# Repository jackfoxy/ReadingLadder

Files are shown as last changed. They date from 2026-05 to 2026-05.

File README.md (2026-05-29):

# ReadingLadder

A one-piece furniture design: a floor-standing **reading lectern** on the front,
**steps** climbing the back to a **top platform** for reaching high shelves, with
a front **book cubby** (3 compartments), a side-loading **under-step shelf**, and
a platform **grab post**.

Modeled in FreeCAD (driven through the AI Copilot MCP server), script-first, with
Git set up to handle `.FCStd` files sanely.

Design spec (inches): 42" deep × 24" wide footprint; steps 3 × (8" rise / 10"
tread) to a platform at 24"; lectern rises to 46" with a reading surface sloping
to a 42" front lip. Modeling units are inches (`CLAUDE.md`).

## Layout

```
.
├── .gitattributes        # routes .FCStd through the rezip clean/smudge filter
├── .gitignore            # backups, locks, python cache, build/ artifacts
├── CLAUDE.md             # conventions loaded by Claude Code each session
├── README.md
├── tools/
│   ├── fcstd-rezip.py    # git clean filter: stores zip entries uncompressed
│   └── setup-filters.sh  # run once per clone to register the filter
├── src/                  # model-generating scripts -- the source of truth
│   ├── reading_ladder_phase1.py        # massing block (side profile, padded 24")
│   ├── reading_ladder_phase2.py        # hollow into 3/4" panels (shell)
│   ├── reading_ladder_phase3a_cubby.py # front 3-compartment book cubby
│   ├── reading_ladder_phase3b_lip.py   # reading-surface front lip
│   ├── reading_ladder_phase3c_sideshelf.py # left under-step side shelf
│   ├── reading_ladder_phase4_grabpost.py   # platform grab post
│   ├── reading_ladder_phase5_export.py # save + export STEP/STL
│   ├── reading_ladder_parts.py         # all components as flat 3/4" solids
│   ├── reading_ladder_drawings.py      # TechDraw pages (view in FreeCAD GUI)
│   ├── gen_drawings_svg.py             # standalone dimensioned shop-drawing SVGs
│   └── diag.py, diag_faces.py          # inspection helpers
├── docs/
│   └── cutlist.md        # component cut list (3/4" ply + lumber, butt joints)
├── models/               # committed .FCStd checkpoints (rebuildable from src/)
│   ├── ReadingLadder.FCStd        # the assembly
│   └── ReadingLadder_Parts.FCStd  # exploded parts + TechDraw pages
└── build/                # exported STEP / STL / SVG -- ignored, regenerable
```

## First-time setup

```bash
git clone git@github.com:jackfoxy/ReadingLadder.git
cd ReadingLadder
bash tools/setup-filters.sh   # register the .FCStd filter in .git/config
```

`setup-filters.sh` registers the rezip filter (`clean` + a pass-through `smudge`,
`required`). The filter *definition* lives in `.git/config`, which is **not**
version-controlled, so every fresh clone runs it once. Without the `smudge`,
`required = true` makes `.FCStd` checkout/restore (and a fresh clone's checkout)
fail — so don't skip this step. `.gitattributes` (tracked) only says *which*
files use the filter, not what it does.

## Building the model

FreeCAD must be running with the AI Copilot workbench and an active document.
Run each phase from the FreeCAD Python console, in order:

```python
exec(open('/abs/path/to/ReadingLadder/src/reading_ladder_phase1.py').read())
# ...phase2, phase3a, phase3c, phase3b, phase4, phase5
```

Each phase prints a status line and (phase 1) saves `models/ReadingLadder.FCStd`.
Phase 5 exports `build/ReadingLadder.{step,stl}`.

## Component schematics

See the cut list in [`docs/cutlist.md`](docs/cutlist.md) and the assembled
drawings in **[`build/ReadingLadder_drawings.pdf`](build/ReadingLadder_drawings.pdf)**
(11 pages, A4 landscape — one dimensioned page per part).

```python
# in FreeCAD: build the parts model + TechDraw pages
exec(open('/abs/path/to/ReadingLadder/src/reading_ladder_parts.py').read())
exec(open('/abs/path/to/ReadingLadder/src/reading_ladder_drawings.py').read())
```

```bash
# standalone (no FreeCAD): printable A4 dimensioned shop drawings -> build/drawings/
python3 src/gen_drawings_svg.py        # 11 per-part SVGs
python3 src/assemble_drawings_pdf.py   # combine into build/ReadingLadder_drawings.pdf
```

The TechDraw pages render when `ReadingLadder_Parts.FCStd` is opened in the
FreeCAD GUI. TechDraw's *headless* SVG export drops view geometry, so the
**printable** drawings come from `gen_drawings_svg.py`, not the TechDraw export.

## Why this shape

`.FCStd` is a binary zip, so Git can't diff or merge it. Two defenses:

1. **The rezip filter** stores the archive uncompressed on the way into Git, so
   successive commits delta-compress well instead of storing whole new copies.
2. **Script-first**: the `src/` scripts are the source of truth — plain text,
   clean diffs, fully regenerable. The `.FCStd` files in `models/` are
   convenience checkpoints; `build/` holds disposable exports (STEP for
   interchange, STL for printing, SVG shop drawings) and is **gitignored** —
   regenerate from `src/` rather than committing it.

## Notes

- The as-built `.FCStd` carries a known **+¾" outward-shell artifact** (phase 2
  shelled outward), so the assembly is ~43.5 × 25.5 × 60" vs the 42 × 24" spec.
  The **component schematics use the nominal spec**, not the as-built solid.
- `models/ReadingLadder.FCStd` is the assembly; `models/ReadingLadder_Parts.FCStd`
  is the flat exploded parts set used for the cut list and drawings.

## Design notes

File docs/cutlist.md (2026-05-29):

# ReadingLadder — Component Cut List

Derived from the **nominal design spec** (not the as-built massing solid, which
carries a +¾" shell artifact). All dimensions in inches.

## Construction assumptions

- **Sheet parts:** ¾" plywood. **Linear parts:** solid lumber.
- **Joinery:** butt joints throughout (glue + fasteners/pocket screws).
- The two **side panels are the outer skin**; every other panel runs **22.5"**
  between them (24 overall − 2 × ¾").
- Dimensions are *face* dimensions. Where two ¾" parts meet, absorb the overlap
  into your chosen joint (dado/rabbet/butt) — figures below assume simple butt.
- Overall assembled envelope: **42" deep × 24" wide × 46" high** (grab post
  extends to **60"**).

## Side-profile polygon (for the side panels)

Cut each side to this outline (X = depth from back, Z = height), inches:

```
(0,0) (0,8) (10,8) (10,16) (20,16) (20,24) (30,24) (30,46) (42,42) (42,0)
```

## Plywood parts (¾")

| ID | Part | Qty | L × W (in) | Notes |
|----|---|----:|---|---|
| A  | Side panel | 2 | 42 × 46 (profile) | Cut to side-profile polygon above. **LEFT** panel only: cut an 18.5 × 14.5 side-shelf opening, located 10.75" from back edge, 0.75" up from bottom. Grain runs vertical. |
| B  | Step tread | 3 | 22.5 × 10 | Horizontal; treads at z = 8, 16, 24 (top = platform). |
| C  | Riser | 3 | 22.5 × 8 | Vertical; risers at x = 0, 10, 20. |
| D  | Lectern back wall | 1 | 22.5 × 22 | Vertical at x = 30, z 24→46; separates platform from lectern. |
| E  | Lectern front | 1 | 22.5 × 42 | Vertical at x = 42. Cut **three cubby openings**, each 21" wide (¾" frame each side): C1 z 0→13, C2 z 13.75→26.5, C3 z 27.25→40. |
| F  | Reading surface | 1 | 22.5 × 12&nbsp;5⁄8 | Sloped top (≈18.4°). Bevel both long edges ≈18° to seat on the lectern-back top (z 46) and meet the front lip. |
| G  | Cubby shelf | 2 | 22.5 × 10.5 | Horizontal dividers inside the cubby, at z = 13 and z = 26.5. Depth = cubby depth. |
| H  | Cubby back *(optional)* | 1 | 22.5 × 40 | Vertical at x = 31.5; boxes the cubby off from the lower carcass. Omit to leave cubby open to the case interior. |
| J  | Bottom panel *(optional)* | 1 | 22.5 × 42 | Closes the underside (the model leaves it open; add for a finished base/dust seal). |

## Lumber parts

| ID | Part | Qty | Section × Length (in) | Notes |
|----|---|----:|---|---|
| K  | Grab post | 1 | 1.5 × 1.5 × 36 | A 2×2 (dresses to 1.5" sq). Mounts at left-front of platform (x≈21, z 24→60); through-tenon or bracket into platform. |
| L  | Front lip | 1 | ¾ × 1.5 × 22.5 | Rail along the front edge of the reading surface; book stop. Can be a plywood rip if preferred. |

## Sheet-goods estimate (¾" ply, 4×8 sheets = 48 × 96")

| Scope | Parts | ≈ Sheets |
|---|---|---:|
| Core (A–G) | 2 sides, 3 treads, 3 risers, lectern front/back, reading surface, 2 shelves | **≈ 2–3** |
| + Optional (H, J) | cubby back, bottom | **+1** |

Two sides dominate the yield (each ~42 × 46). Nest the small parts (treads,
risers, shelves) into the offcuts around the side profiles.

## Lumber estimate

- One **8' 2×2** covers the grab post (K) with margin.
- Front lip (L) from a 2' offcut of lumber or a ¾" ply rip.

## Not itemized

Fasteners, glue, cleats/glue-blocks, finish, and edge-banding for exposed
plywood edges — add per your build method.

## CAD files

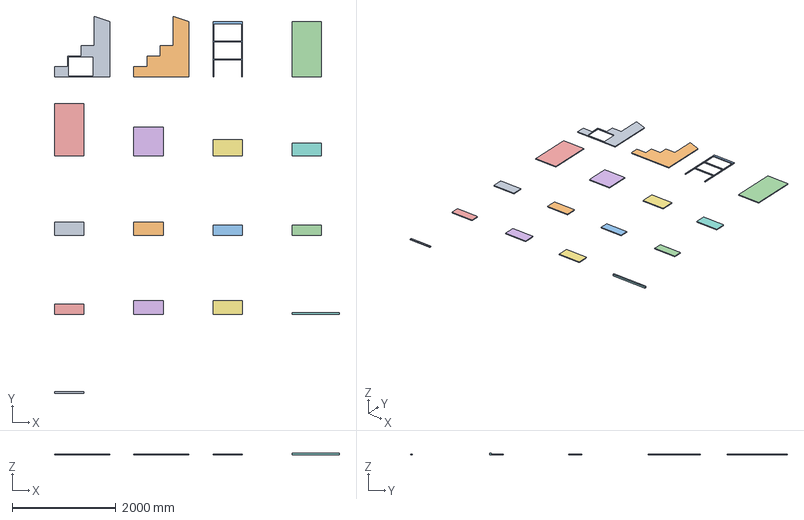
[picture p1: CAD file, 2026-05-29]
models/ReadingLadder_Parts.FCStd
5486.4 x 7264.4 x 38.1 mm
A_Side_L
A_Side_R
E_LecternFront
J_Bottom
H_CubbyBack
D_LecternBack
F_ReadingSurface
B_Tread_1
B_Tread_2
B_Tread_3
C_Riser_1
C_Riser_2
C_Riser_3
G_CubbyShelf_1
G_CubbyShelf_2
K_GrabPost
L_FrontLip

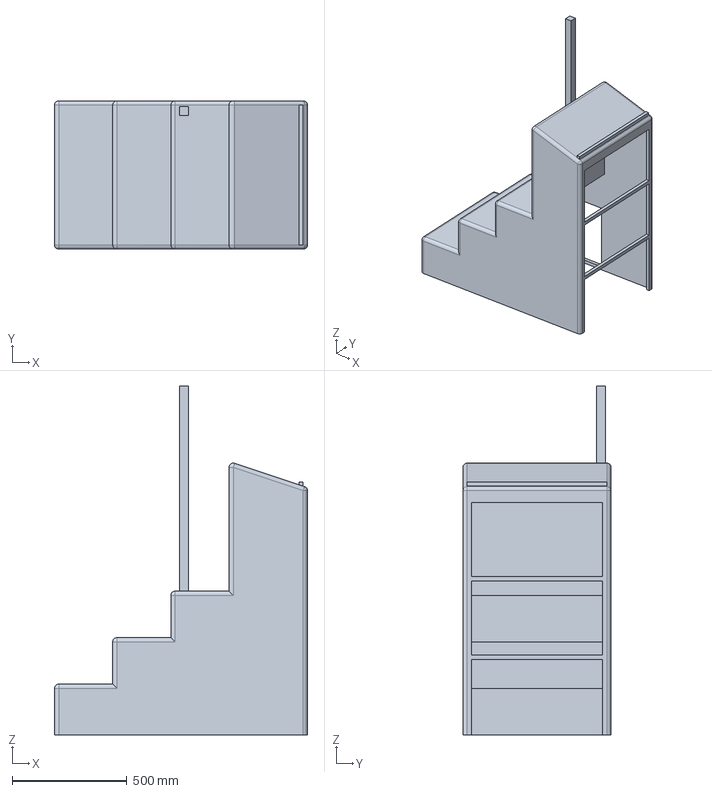
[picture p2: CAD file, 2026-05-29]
models/ReadingLadder.FCStd
1104.9 x 647.7 x 1524.0 mm

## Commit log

2026-05-29 Add ReadingLadder phase 1 massing block
    Side-profile polygon (10 pts, XZ plane) padded 24" wide into a solid
    massing block. Source script in src/, FCStd checkpoint in models/.
    [ReadingLadder.FCStd]
2026-05-29 ReadingLadder phase 2: hollow into 3/4" panels
    PartDesign::Thickness shell ("Panels") removes the bottom face and
    leaves a 3/4" wall on all other faces. Solid 24192 -> shell 3992 in^3.
    Adds face-enumeration diagnostic used to locate the bottom face.
    [ReadingLadder.FCStd]
2026-05-29 ReadingLadder phase 3a: front book-cubby with two shelves
    Three stacked rectangles pocketed 10.5" into the front face; the 3/4"
    gaps between them form two shelf panels, giving three compartments
    (13" / 12.75" / 12.75", 22.5" wide) with the lowest at the floor.
    Shell 3992 -> 3342 in^3.
    [ReadingLadder.FCStd]
2026-05-29 ReadingLadder phase 3c: side-loading shelf under steps 2 & 3
    Opens the left (y=0) side panel over the under-step-2 footprint into the
    existing hollow void, making one side-access compartment: 18.5" wide x
    14.5" tall x ~22.5" deep, 3/4" back wall retained. 3342 -> 3141 in^3.
    [ReadingLadder.FCStd]
2026-05-29 ReadingLadder phase 3b: front lip on reading surface
    Full-width 3/4"-deep rail padded along the front-top edge (z 42->43.5),
    fusing with the sloped reading surface as a book stop. 3141 -> 3154 in^3.
    Completes phase 3 (cubby + side shelf + lip).
    [ReadingLadder.FCStd]
2026-05-29 ReadingLadder phase 4: platform grab post
    1.5" square newel padded 36" up from the platform top (z 24->60) at the
    left-front corner, fused to the platform, to steady yourself reaching
    high shelves. Edge chamfers skipped per design call. 3154 -> 3233 in^3.
    [ReadingLadder.FCStd]
2026-05-29 ReadingLadder phase 5: final checkpoint + STEP/STL export
    Export script writes build/ReadingLadder.step (interchange) and .stl
    (printing) from the body tip, and re-saves the .FCStd. build/ left
    untracked as disposable per project convention.
    Note: accepted a known +3/4" outward-shell deviation (phase 2 Thickness
    offset outward); finished piece is ~43.5x25.5x60 vs the 42x24 spec, and
    the cubby/side shelf open into the shared hollow rather than clean-depth
    boxes. Recorded for future correction.
    [ReadingLadder.FCStd]
2026-05-29 Update hardcoded paths after folder rename to ReadingLadder
    Project folder renamed freecad-mcp -> ReadingLadder. Updated the absolute
    paths in all phase scripts (exec headers, phase1 saveAs target, phase5
    build dir). Also re-registered the rezip clean filter in .git/config to
    the new path via tools/setup-filters.sh.
2026-05-29 Add pass-through smudge to rezip filter for clone safety
    The fcstd-rezip filter was clean-only with required=true, so Git's
    insistence on a smudge made checkout/restore of any .FCStd fail -- and
    a fresh clone's initial checkout with it. Add a 'cat' pass-through
    smudge (the clean filter already stores a valid uncompressed zip, so no
    transform is needed on the way out). Now setup-filters.sh alone makes a
    clone fully working.
2026-05-29 Add component cut list (nominal spec, 3/4" ply + lumber)
    Parts breakdown for fabrication: side profiles, treads, risers, lectern
    front/back, reading surface, cubby shelves (+optional cubby back/bottom),
    grab post and front lip. Derived from nominal spec, not the as-built
    +3/4" solid. Stage 1 of "cut list + 2D drawings".
2026-05-29 Add component parts model + shop drawings (stage 2)
    - reading_ladder_parts.py: builds all 17 component solids (flat, 3/4")
    in a separate ReadingLadder_Parts doc; nominal spec, butt joints.
    - reading_ladder_drawings.py: builds per-part TechDraw pages in that doc
    (render in the FreeCAD GUI). Note: TechDraw's headless SVG export drops
    view geometry, so it is not the source of printable drawings.
    - gen_drawings_svg.py: standalone (no FreeCAD) generator for the printable
    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
    [ReadingLadder_Parts.FCStd]
2026-05-29 Commit STEP/STL exports from phase 5
    build/ReadingLadder.step (CAD interchange) and .stl (3D printing) of the
    finished assembly solid. Reproducible via reading_ladder_phase5_export.py.
    [ReadingLadder.step, ReadingLadder.stl]
2026-05-29 Ignore build/ artifacts going forward
    Uncomment the scaffold's /build/, *.stl, *.step, *.stp ignore rules so
    new exports aren't staged accidentally. Already-tracked build files stay
    tracked (gitignore only affects untracked paths).
2026-05-29 Untrack build/ artifacts (keep on disk, in history)
    Stop tracking the STEP/STL and shop-drawing SVGs so build/ stays lean and
    free of binary churn; they remain on disk and in history (commit 17a2113),
    and regenerate via reading_ladder_phase5_export.py / gen_drawings_svg.py.
    [ReadingLadder.step, ReadingLadder.stl]
2026-05-29 Rewrite README for the ReadingLadder project layout
    Replace the generic scaffold README: describe the design, the actual
    src/ phase + parts + drawings scripts, docs/cutlist.md, both .FCStd
    checkpoints, and build/ now ignored. Update setup notes for the
    clean+smudge filter and the build/drawings workflow. Note the known
    +3/4" shell artifact and that schematics use nominal spec.
2026-05-29 Enlarge drawing titleblock so multi-line notes fit
    Bump titleblock height 34->42mm and tighten note spacing so 4-line note
    blocks (e.g. the side panel) stay inside the border. Verified rendering
    in a browser (headless Firefox).
2026-05-29 Add PDF assembly for the shop drawings
    assemble_drawings_pdf.py renders the 11 drawing SVGs at 254 dpi (via
    headless Firefox, vector scaled through an <img> wrapper) and combines
    them with Pillow into build/ReadingLadder_drawings.pdf (A4 landscape,
    cut-list order A..L). Output stays in the ignored build/ dir.
2026-05-29 Commit assembled shop-drawings PDF for sharing
    build/ReadingLadder_drawings.pdf (11 pages, A4 landscape) force-added
    past the build/ ignore rule so it's shareable without regenerating.
    Reproducible via src/assemble_drawings_pdf.py.
2026-05-29 README: link the cut list and assembled drawings PDF
    Add links to docs/cutlist.md and build/ReadingLadder_drawings.pdf in the
    Component schematics section, and document the assemble step.
2026-05-29 Strip FreeCAD thumbnail in rezip filter (going forward)
    The clean filter now drops thumbnails/Thumbnail.png -- FreeCAD regenerates
    it every save (binary churn). Applies to future commits; existing
    committed thumbnails left as-is per request.
2026-05-29 Renormalize .FCStd to drop committed thumbnails
    Re-run the rezip filter over the tracked .FCStd files so their stored
    blobs lose thumbnails/Thumbnail.png, clearing the dirty working-tree
    status. Files still open in FreeCAD (thumbnail is optional).
    [ReadingLadder.FCStd, ReadingLadder_Parts.FCStd]
